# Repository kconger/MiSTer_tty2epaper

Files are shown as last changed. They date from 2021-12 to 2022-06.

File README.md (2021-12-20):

[MiSTer_tty2epaper](https://github.com/kconger/MiSTer_tty2epaper) is an hardware and software module for the [MiSTer FPGA](https://github.com/MiSTer-devel) with [MiSTer Multisystem](https://rmcretro.store/multisystem-board-only/)

This module displays the logo of current the running core on a 2.13"(104x212) 3 Color ePaper display. If the current core logo isn't available the MiSTer logo is displayed.

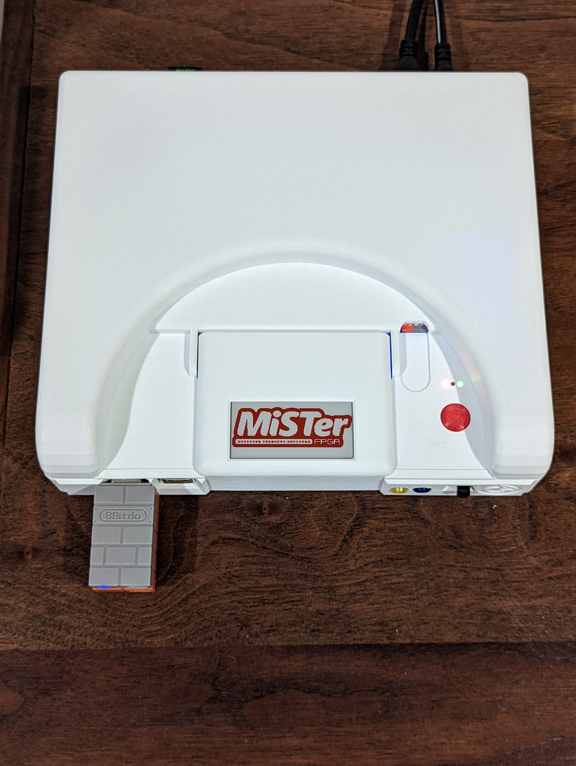
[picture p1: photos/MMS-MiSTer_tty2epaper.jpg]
MMS Install


Requirements
-------

Hardware
- Waveshare 2.13"(104x212) 3 Color(BWR) ePaper display HAT.
- Adafruit QT Py - SAMD21 Dev Board or Seeduino XIAO M0
- MiSTer_tty2epaper PCB
- 40pin header
- Short USB-C male to USB-A male cable
- 3D printed part

Software
- Arduino
- GxEPD2 library
- Proper board support package for your chossen MCU

Linux/MiSTer service code from the [MiSTer_tty2oled](https://github.com/venice1200/MiSTer_tty2oled) project with minor modifications.

Install
-------

1. **MiSTer Setup**

Copy tty2epaper folder to root of your MiSTer_Data partition.

Add the following to the bottom of MiSTer_Data/linux/user-startup.sh

```
/media/fat/tty2epaper/S60tty2epaper start
```

2. **Hardware Setup**

Flash the Arduino sketch to the board using Arduino IDE

3. **Assemble**

Solder the 40pin header and MCU to the PCB.  The longer pins of the 40pin connector should be inserted into the side of the PCB labeled "Waveshare Hat".

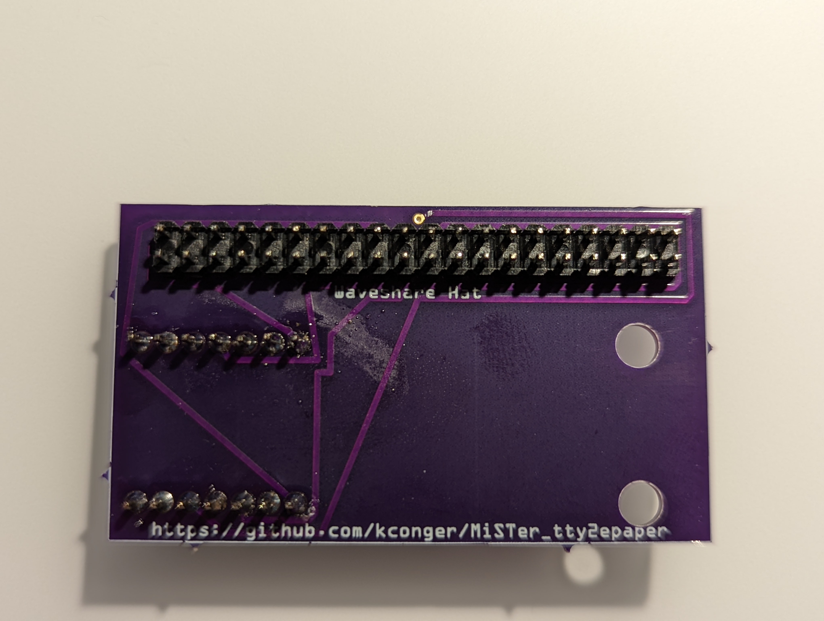
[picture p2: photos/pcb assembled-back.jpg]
PCB Build Back


The MCU should be soldered onto the opposite side of the PCB.

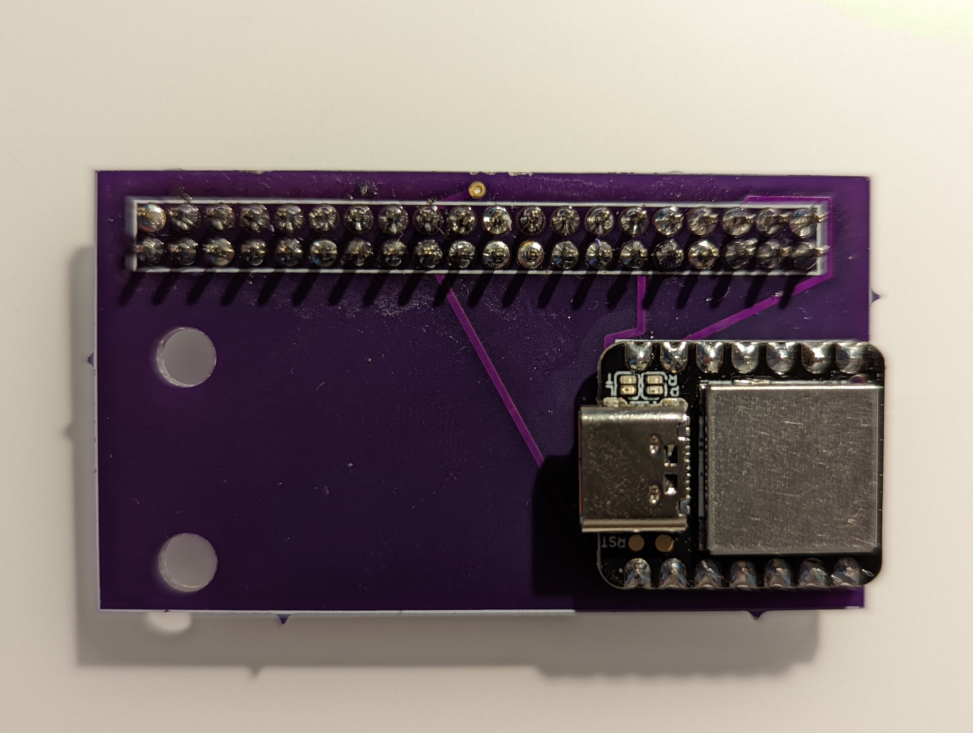
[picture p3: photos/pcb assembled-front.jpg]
PCB Build Front


Connect the ePaper Hat to the PCB you just assembled.

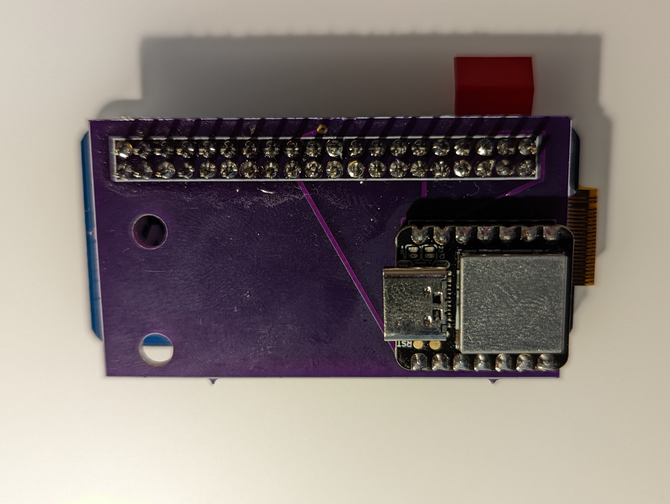
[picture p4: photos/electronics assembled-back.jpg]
Electronics Assembled


Slide the module into the 3D printer case and plug in the USB-C side of the cable into the MCU.

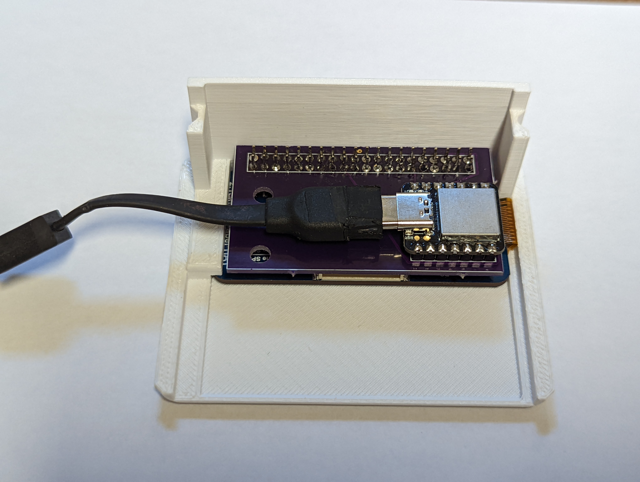
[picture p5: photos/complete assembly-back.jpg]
Module Assembled


Plug in USB cable and install MiSTer_tty2epaper module into MiSTer Multisystem case.

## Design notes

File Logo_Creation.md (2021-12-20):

Howto create new logos

Requirements
-------

Software
- [Inkscape](https://inkscape.org/)
- [Img2Lcd](https://www.waveshare.com/wiki/File:Image2Lcd.7z)

Logo Creation
-------

Open the "104x212_template.svg" in Inkscape.  

Import or create your logo and fit within the document.

Export a PNG of your design for each color.

Convert the PNG to JPG.

In Img2LCD open each JPG and convert with the following settings:

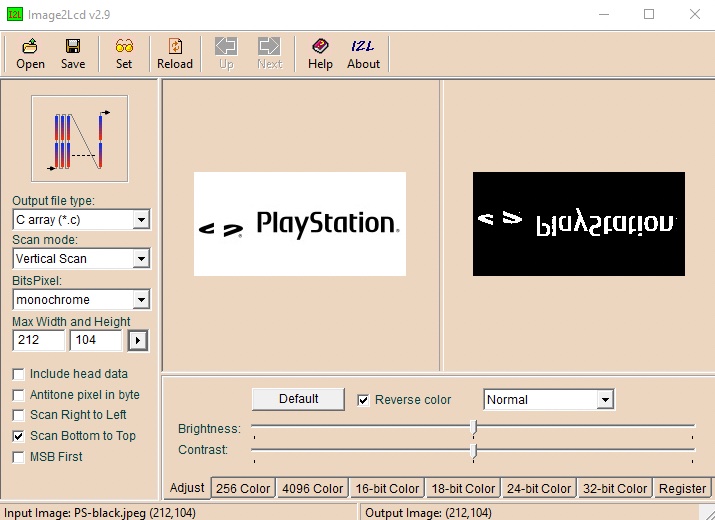
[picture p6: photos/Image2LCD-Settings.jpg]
Img2LCD Settings


Make a copy of an existing Core logo.h file for your new logo. Rename all the variable names with your new logo name. Copy the array contents of the Img2LCD created .c files into the arrays of the new logo.h file. 

Add an include to the new logo in the "logo.h" file.

Add a case to display the new logo in "MiSTer_tty2epaper.ino"

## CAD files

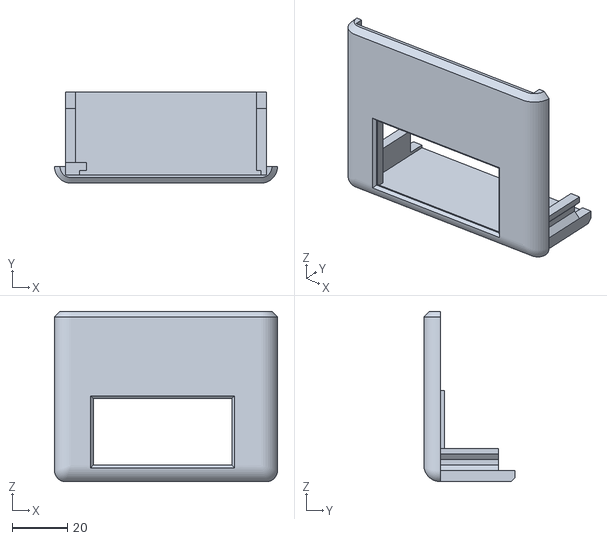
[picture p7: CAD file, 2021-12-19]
models/MMS-tty2epaper.stl
80.5 x 33.0 x 61.5

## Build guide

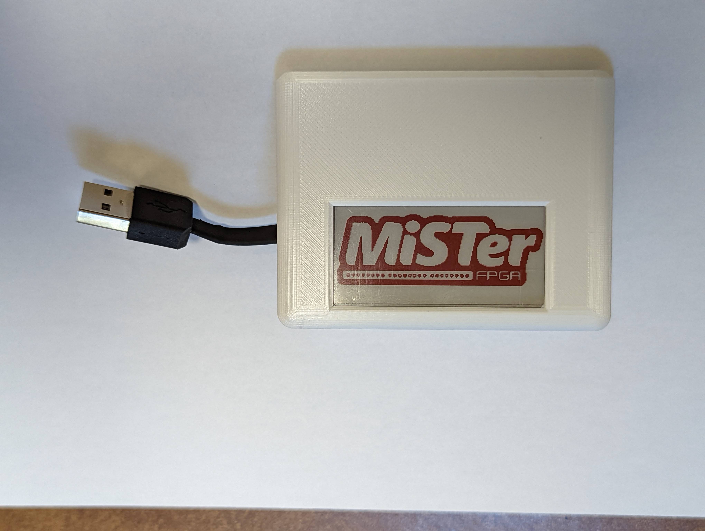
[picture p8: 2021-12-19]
photos/complete assembly-front.jpg

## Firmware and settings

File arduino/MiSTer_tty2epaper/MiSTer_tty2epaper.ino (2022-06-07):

/**
 * MiSTer_tty2epaper
 * 
 * Displays logo of active MiSTer Core, if logo doesn't exist 
 * for the core it displays the MiSTer logo.
 * 
 * Send "<CORENAME>\n" over serial.
 * 
 */

//GxEPD2 Setup
#include <GxEPD2_3C.h>

//GxEPD2 Display Settings
#define GxEPD2_DISPLAY_CLASS GxEPD2_3C
#define GxEPD2_DRIVER_CLASS GxEPD2_213_Z19c // GDEW0213Z19 104x212, UC8151D

//GxEPD2 MCU Settings
#define MAX_DISPLAY_BUFFER_SIZE 15000ul // ~15k is a good compromise
#define MAX_HEIGHT(EPD) (EPD::HEIGHT <= (MAX_DISPLAY_BUFFER_SIZE / 2) / (EPD::WIDTH / 8) ? EPD::HEIGHT : (MAX_DISPLAY_BUFFER_SIZE / 2) / (EPD::WIDTH / 8))
GxEPD2_DISPLAY_CLASS<GxEPD2_DRIVER_CLASS, MAX_HEIGHT(GxEPD2_DRIVER_CLASS)> display(GxEPD2_DRIVER_CLASS(/*CS=4*/ 4, /*DC=*/ 2, /*RST=*/ 1, /*BUSY=*/ 0));

//Logos
#include "logos/logo.h"
#include "logos/104x212/logos-104x212.h"  //104x212 3 Color Logos

String command = "";
String previousCommand = "";
bool prevMiSTerLogo = true;  // Help prevent unecessary MiSTer logo redraws

void setup()
{
  Serial.begin(115200);
  Serial.println();

  delay(100);
  //display.init(115200);
  display.init(115200, true, 2, false);

  drawLogo(MISTER_LOGO);

  Serial.println("Startup Complete");
}

void loop()
{
  byte ch;
  if (Serial.available()) {
      ch = Serial.read();
      command += (char)ch;
      if (ch=='\n') {
         Serial.println("Command Received");
         command.trim();
         Serial.println(command);
         if (previousCommand != command){
             if (command == "AcornElectron"){
                 prevMiSTerLogo = false;
                 drawLogo(AcornElectron_LOGO);
             } else if (command == "Amstrad"){
                 prevMiSTerLogo = false;
                 drawLogo(Amstrad_LOGO);
             } else if (command == "AO486"){
                 prevMiSTerLogo = false;
                 drawLogo(AO486_LOGO);
             } else if (command == "ARCHIE"){
                 prevMiSTerLogo = false;
                 drawLogo(Archie_LOGO);
             } else if (command == "Arcadia"){
                 prevMiSTerLogo = false;
                 drawLogo(Arcadia_LOGO);
             } else if (command == "Astrocade"){
                 prevMiSTerLogo = false;
                 drawLogo(Astrocade_LOGO);
             } else if (command == "ATARI5200"){
                 prevMiSTerLogo = false;
                 drawLogo(ATARI5200_LOGO);
             } else if (command == "ATARI7800"){
                 prevMiSTerLogo = false;
                 drawLogo(ATARI7800_LOGO);
             } else if (command == "AtariLynx"){
                 prevMiSTerLogo = false;
                 drawLogo(AtariLynx_LOGO);
             } else if (command == "AtariST"){
                 prevMiSTerLogo = false;
                 drawLogo(AtariST_LOGO);
             } else if (command == "BBCMicro"){
                 prevMiSTerLogo = false;
                 drawLogo(BBCMicro_LOGO);
             } else if (command == "ChannelF"){
                 prevMiSTerLogo = false;
                 drawLogo(ChannelF_LOGO);
             } else if (command == "Coleco"){
                 prevMiSTerLogo = false;
                 drawLogo(ColecoVision_LOGO);
             } else if (command == "C16"){
                 prevMiSTerLogo = false;
                 drawLogo(Commodore_LOGO);
             } else if (command == "C64"){
                 prevMiSTerLogo = false;
                 drawLogo(Commodore_LOGO);
             } else if (command == "GameNWatch"){
                 prevMiSTerLogo = false;
                 drawLogo(GAW_LOGO);
             } else if (command == "GAMEBOY"){
                 prevMiSTerLogo = false;
                 drawLogo(GAMEBOY_LOGO);
             } else if (command == "GAMEBOY2P"){
                 prevMiSTerLogo = false;
                 drawLogo(GAMEBOY_LOGO);
             } else if (command == "GBA"){
                 prevMiSTerLogo = false;
                 drawLogo(GBA_LOGO);
             } else if (command == "GBA2P"){
                 prevMiSTerLogo = false;
                 drawLogo(GBA_LOGO);
             } else if (command == "Genesis"){
                 prevMiSTerLogo = false;
                 drawLogo(Genesis_LOGO);
             } else if (command == "S32X"){
                 prevMiSTerLogo = false;
                 drawLogo(GEN32X_LOGO);
             } else if (command == "Intellivision"){
                 prevMiSTerLogo = false;
                 drawLogo(Intellivision_LOGO);
             } else if (command == "Jaguar"){
                 prevMiSTerLogo = false;
                 drawLogo(Jaguar_LOGO);
             } else if (command == "MegaCD"){
                 prevMiSTerLogo = false;
                 drawLogo(MEGACD_LOGO);
             } else if (command == "Minimig"){
                 prevMiSTerLogo = false;
                 drawLogo(Minimig_LOGO);
             } else if (command == "MSX"){
                 prevMiSTerLogo = false;
                 drawLogo(MSX_LOGO);
             } else if (command == "NEOGEO"){
                 prevMiSTerLogo = false;
                 drawLogo(NEOGEO_LOGO);
             } else if (command == "NES"){
                 prevMiSTerLogo = false;
                 drawLogo(NES_LOGO);
             } else if (command == "ODYSSEY2"){
                 prevMiSTerLogo = false;
                 drawLogo(Odyssey2_LOGO);
             } else if (command == "PC8801"){
                 prevMiSTerLogo = false;
                 drawLogo(PC8801_LOGO);
             } else if (command == "PSX"){
                 prevMiSTerLogo = false;
                 drawLogo(PSX_LOGO);
             } else if (command == "RX78"){
                 prevMiSTerLogo = false;
                 drawLogo(RX78_LOGO);
             } else if (command == "Saturn"){
                 prevMiSTerLogo = false;
                 drawLogo(Saturn_LOGO);
             } else if (command == "SMS"){
                 prevMiSTerLogo = false;
                 drawLogo(SMS_LOGO);
             } else if (command == "SNES"){
                 prevMiSTerLogo = false;
                 drawLogo(SNES_LOGO);
             } else if (command == "Sord M5"){
                 prevMiSTerLogo = false;
                 drawLogo(Sord_LOGO);
             } else if (command == "Spectrum"){
                 prevMiSTerLogo = false;
                 drawLogo(ZXSpectrum_LOGO);
             } else if (command == "TGFX16"){
                 prevMiSTerLogo = false;
                 drawLogo(TGFX16_LOGO);
             } else if (command == "TI-99_4A"){
                 prevMiSTerLogo = false;
                 drawLogo(TI994a_LOGO);
             } else if (command == "VC4000"){
                 prevMiSTerLogo = false;
                 drawLogo(VC4000_LOGO);
             } else if (command == "VIC20"){
                 prevMiSTerLogo = false;
                 drawLogo(VIC20_LOGO);
             } else if (command == "VECTREX"){
                 prevMiSTerLogo = false;
                 drawLogo(Vectrex_LOGO);
             } else if (command == "WonderSwan"){
                 prevMiSTerLogo = false;
                 drawLogo(WonderSwan_LOGO);
             } else if (command == "X68000"){
                 prevMiSTerLogo = false;
                 drawLogo(X68000_LOGO);
             } else if (command == "Zet98"){
                 prevMiSTerLogo = false;
                 drawLogo(PC9801_LOGO);
             } else {
                 if (!prevMiSTerLogo) {
                     prevMiSTerLogo = true;
                     drawLogo(MISTER_LOGO);
                 }
             }
         }
         previousCommand = command;
         command = "";
      }
   }
}

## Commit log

2021-12-05 Initial model for MMS module
    [MMS-epaper.3mf]
2021-12-06 Added photos of assembled hardware
2021-12-18 Model doesn't work, verified with a board.
    [MMS-epaper.3mf]
2021-12-19 Finished model and updated pictures
    [MMS-tty2epaper.stl]
